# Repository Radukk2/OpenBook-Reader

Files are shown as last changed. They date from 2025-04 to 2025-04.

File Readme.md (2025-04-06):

# OpenBook Reader - Project
Block Chart : Block_chart.png file in the root of the directory

Bill of Materials : The bill of materials file can be found at /Manufacturing/Bom.csv

Hardware description
1. Microcontroller - ESP32-C6-WROOM-1-N8
    CPU: 32-bit RISC-V single-core @ up to 160MHz
    Memory: 320KB ROM, 512KB HP SRAM, 16KB LP SRAM
    Connectivity: Wi-Fi 6, Bluetooth LE 5.0
    Interfaces: GPIO, SPI, UART, I2C, PWM   
    Operating Voltage: 3.3V

   - The given microcontroller uses the following power modes: 
        When the device is active it consumes from 160 to 260 mA.
        When modem sleeps it ranges from 3 to 20 mA.
        On light the device consumes 0.8 mA.
        In Deep-sleep mode it consumes 10 μA.
        Hibernation modes consumes 2.5 μA.

2. Display Interface 7.5" E-Paper Display
    - Interface: SPI via FPC connector
    - Pins:   EPD_CS: GPIO10
            EPD_DC: GPIO5
            EPD_RST: GPIO23
            EPD_BUSY: GPIO3
            MOSI, SCK: Shared with SD card
            Used pins : Pins.xlsx  provieds the full ecplination

    The reasons why we use ePaper is for: 
                                        - ultra-low power consumption
                                        - excellent sunlight readability
3. Storage Solutions
    - MicroSD Card with the SPI interface.
    - 64MB NOR Flash with the same SPI interface.

4. Real time clocks
    We use a DS3231SN model for its high accuracy, backup supported battery.

5. Power Management
    USB-C Interface 
    MCP73831 - Li-Po Battery Charging that is used for charging

6. Buttons
    There are also 3 buttons: reset, boot and change. These are used for user's interaction with the device.

Used Pins: Described fully in Pins.xlsx

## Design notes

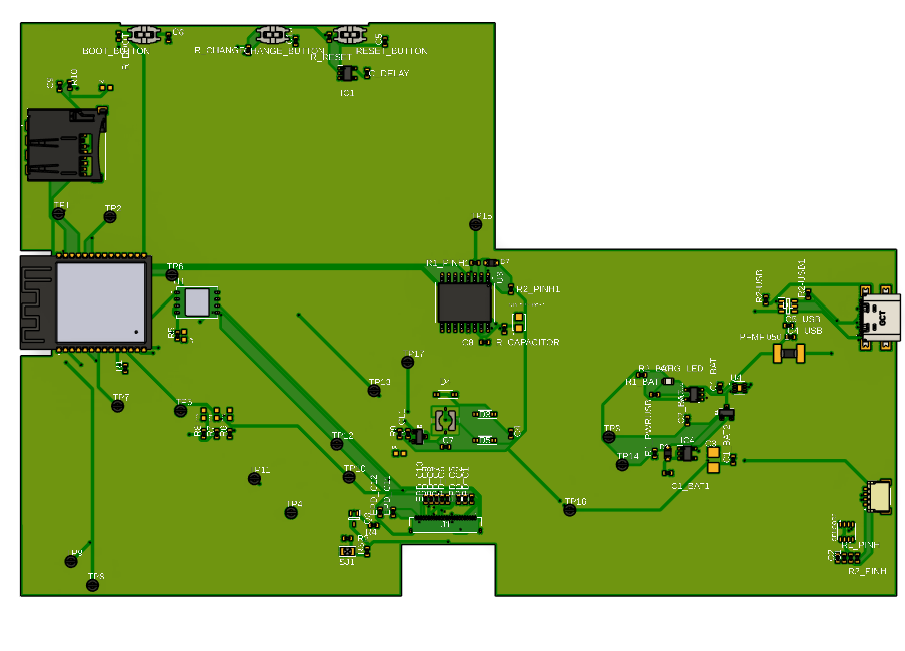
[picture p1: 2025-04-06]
Images/board1.png

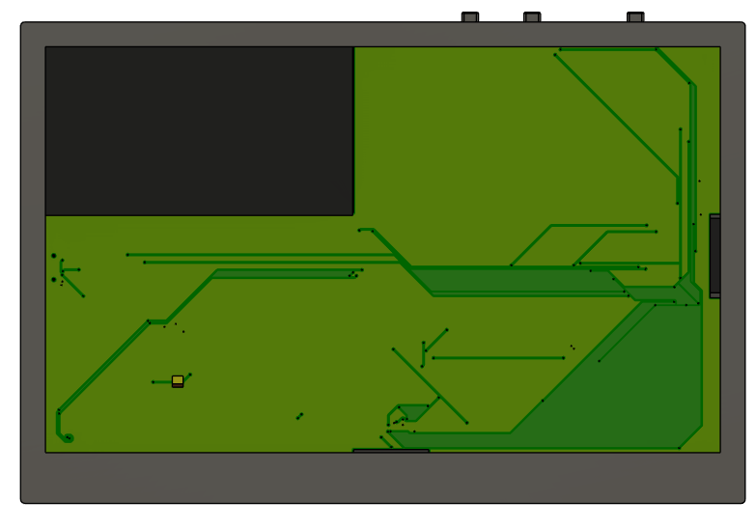
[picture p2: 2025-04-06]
Images/battery_and_front_no screen.png

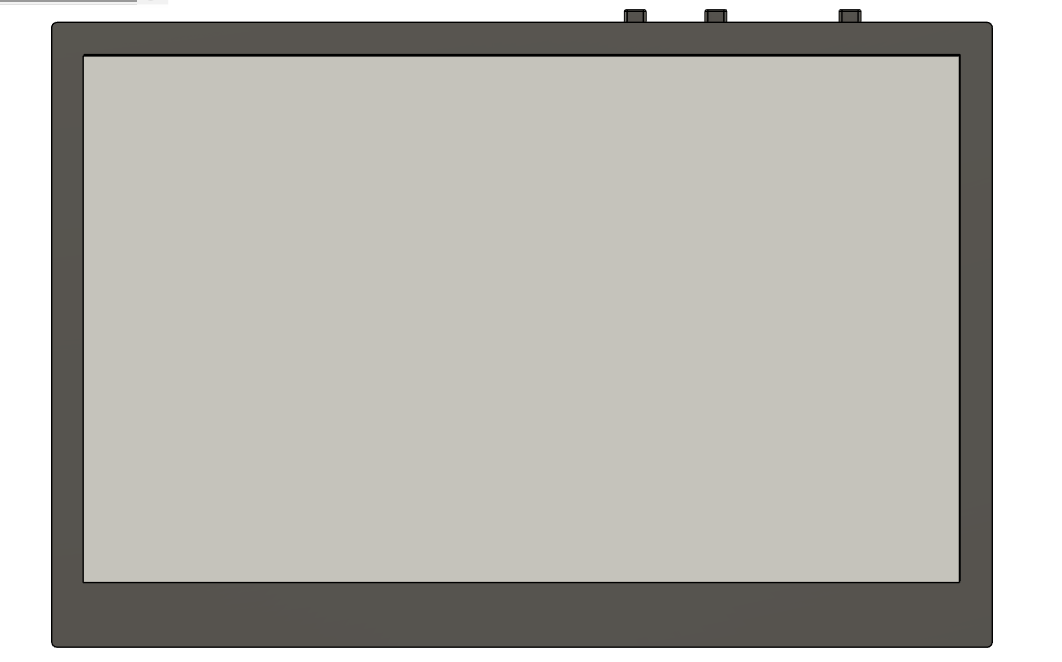
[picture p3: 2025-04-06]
Images/Front.png

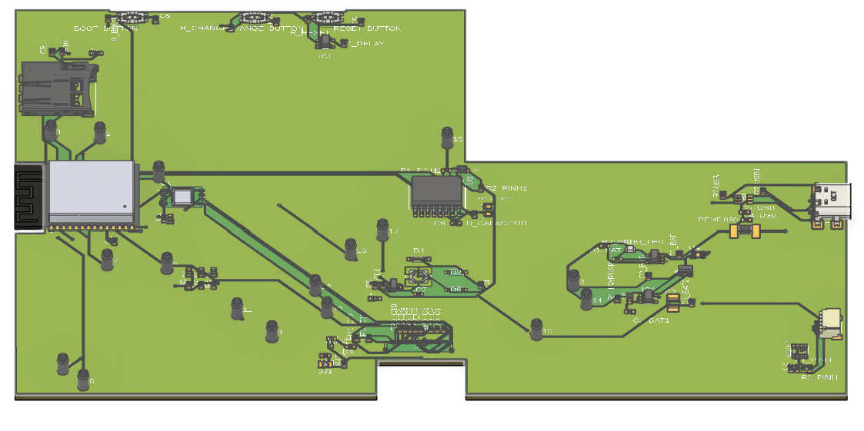
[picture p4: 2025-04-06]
Images/board2.png

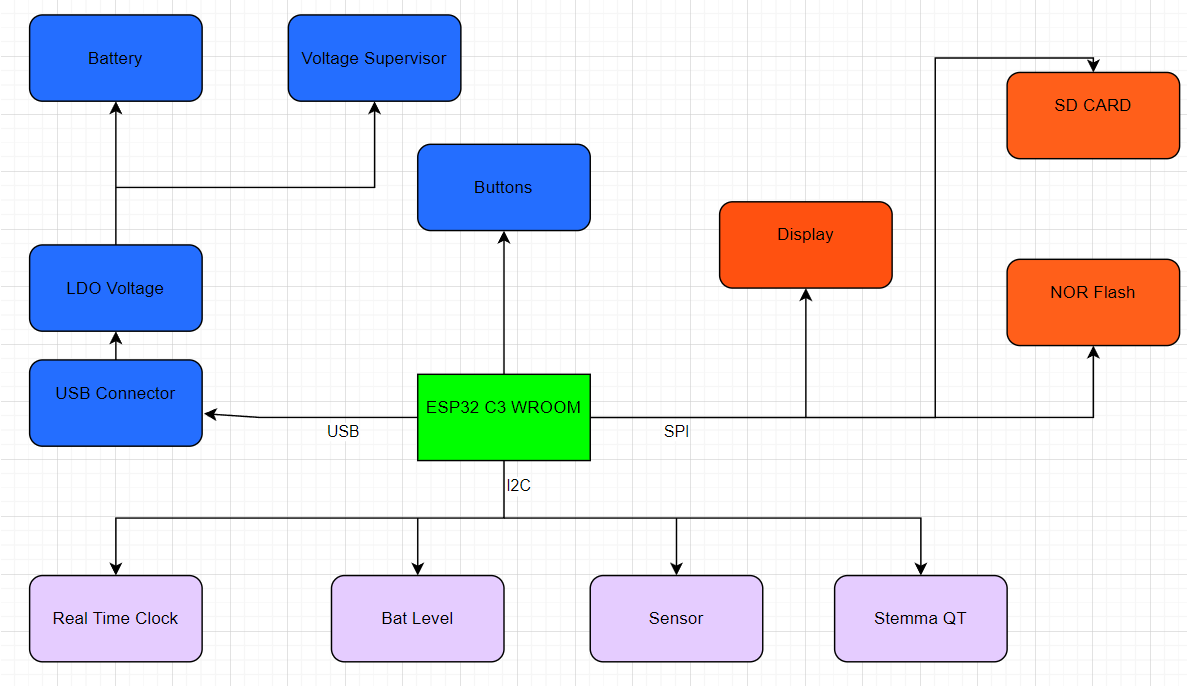
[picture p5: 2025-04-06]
Block_Chart.png

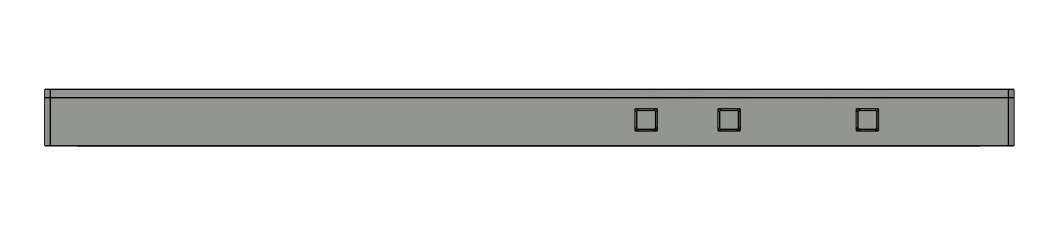
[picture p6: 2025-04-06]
Images/buttons.png

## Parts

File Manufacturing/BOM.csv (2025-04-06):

Qty | Value | Device | Package | Parts | Description | ARROW_PART_NUMBER | ARROW_PRICE-STOCK | AVAILABILITY | CENTROID_NOT_SPECIFIED | CHECK_PRICES | COPYRIGHT | DATASHEET | DESCRIPTION | DIGIKEY_DESCRIPTION | DIGIKEY_PART_NUMBER | HEIGHT | LEAD_FREE | MANUFACTURER_NAME | MANUFACTURER_PART_NUMBER | MF | MFR_NAME | MOUSER_PART_NUMBER | MOUSER_PRICE-STOCK | MOUSER_TESTING_PART_NUMBER | MOUSER_TESTING_PRICE-STOCK | MP | MPN | PACKAGE | POPULARITY | PREFIX | PRICE | PROD_ID | PURCHASE-URL | ROHS | SNAPEDA_LINK | SPICEMODEL | SPICEPREFIX | TEMPERATURE_RANGE_HIGH | TEMPERATURE_RANGE_LOW | TP_SIGNAL_NAME | VALUE
1 |  | ADAFRUIT_LEDCHIP-LED0603 | ADAFRUIT_CHIP-LED0603 | CHG_LED | LED |  |  |  |  | https://www.snapeda.com/parts/KP-1608SURCK/Kingbright/view-part/?ref=search&t=LED%200603
5 |  | EAGLE-LTSPICE_CC0402 | EAGLE-LTSPICE_C0402 | C1, C2, C5, C7, EPD_C9 | CAPACITOR, European symbol |  |  |  |  | https://grabcad.com/library/solder-jumpers-1 |  |  |  |  |  |  |  |  |  |  |  |  |  |  |  |  |  |  |  |  |  |  |  |  |  | NONE | C
1 |  | ESP32_WROVER_EAGLE-LTSPICE_RR0402 | ESP32_WROVER_EAGLE-LTSPICE_R0402 | R2 | RESISTOR, European symbol |  |  |  |  | https://eu.mouser.com/ProductDetail/KEMET/C0805C104K8RACAUTO?qs=ds50AKTGxA8vmn6TMGYnqg%3D%3D |  |  |  |  |  |  |  |  |  |  |  |  |  |  |  |  |  |  |  |  |  |  |  |  |  | NONE | R
1 |  | SJ | SJ | SJ1 | SMD solder JUMPER |  |  |  |  | https://componentsearchengine.com/part-view/R0402%201%25%20100%20K%20(RC0402FR-07100KL)/YAGEO |  |  |  |  |  |  |  |  |  |  |  |  |  |  |  |  |  |  | 3
1 | 0.1uF/50V | EAGLE-LTSPICE_CC0402 | EAGLE-LTSPICE_C0402 | EPD_C5 | CAPACITOR, European symbol |  |  |  |  | https://componentsearchengine.com/part-view/R0402%201%25%20100%20K%20(RC0402FR-07100KL)/YAGEO |  |  |  |  |  |  |  |  |  |  |  |  |  |  |  |  |  |  |  |  |  |  |  |  |  | NONE | C
1 | 0.47 | ESP32_WROVER_EAGLE-LTSPICE_RR0402 | ESP32_WROVER_EAGLE-LTSPICE_R0402 | R3 | RESISTOR, European symbol |  |  |  |  | https://eu.mouser.com/ProductDetail/KEMET/C0805C104K8RACAUTO?qs=ds50AKTGxA8vmn6TMGYnqg%3D%3D |  |  |  |  |  |  |  |  |  |  |  |  |  |  |  |  |  |  |  |  |  |  |  |  |  | NONE | R
1 | 100K | ESP32_WROVER_EAGLE-LTSPICE_RR0402 | ESP32_WROVER_EAGLE-LTSPICE_R0402 | R1_PWRUSB | RESISTOR, European symbol |  |  |  |  | https://www.snapeda.com/parts/20TDC100MYF/Panasonic/view-part/ |  |  |  |  |  |  |  |  |  |  |  |  |  |  |  |  |  |  |  |  |  |  |  |  |  | NONE | R
5 | 100nF | EAGLE-LTSPICE_CC0402 | EAGLE-LTSPICE_C0402 | C4_USB, C6, C8, C9, C_DELAY | CAPACITOR, European symbol |  |  |  |  | https://componentsearchengine.com/part-view/R0402%201%25%20100%20K%20(RC0402FR-07100KL)/YAGEO |  |  |  |  |  |  |  |  |  |  |  |  |  |  |  |  |  |  |  |  |  |  |  |  |  | NONE | C
1 | 100uF | RCL_CPOL-EUCT3528 | RCL_CT3528 | C3 | POLARIZED CAPACITOR, European symbol |  |  |  |  | https://eu.mouser.com/ProductDetail/KEMET/C0805C104K8RACAUTO?qs=ds50AKTGxA8vmn6TMGYnqg%3D%3D |  |  |  |  |  |  |  |  |  |  |  |  |  |  |  |  |  |  | 0 |  |  |  |  |  |  |  | C
16 | 10K | ESP32_WROVER_EAGLE-LTSPICE_RR0402 | ESP32_WROVER_EAGLE-LTSPICE_R0402 | R1, R1_PINH, R1_PINH1, R2_PINH, R2_PINH1, R4, R5, R6, R7, R8, R9, R10, R_BOOT, R_CHANGE, R_CL1, R_RESET | RESISTOR, European symbol |  |  |  |  | https://store.comet.srl.ro/Catalogue/Product/43497/ |  |  |  |  |  |  |  |  |  |  |  |  |  |  |  |  |  |  |  |  |  |  |  |  |  | NONE | R
1 | 10nF | EAGLE-LTSPICE_CC0402 | EAGLE-LTSPICE_C0402 | C10 | CAPACITOR, European symbol |  |  |  |  | https://componentsearchengine.com/part-view/R0402%201%25%20100%20K%20(RC0402FR-07100KL)/YAGEO |  |  |  |  |  |  |  |  |  |  |  |  |  |  |  |  |  |  |  |  |  |  |  |  |  | NONE | C
1 | 10uF/50 | EAGLE-LTSPICE_CC0402 | EAGLE-LTSPICE_C0402 | EPD_C10 | CAPACITOR, European symbol |  |  |  |  | https://eu.mouser.com/ProductDetail/KEMET/C0805C104K8RACAUTO?qs=ds50AKTGxA8vmn6TMGYnqg%3D%3D |  |  |  |  |  |  |  |  |  |  |  |  |  |  |  |  |  |  |  |  |  |  |  |  |  | NONE | C
1 | 112A-TAAR-R03_ATTEND | 112A-TAAR-R03_ATTEND | 112ATAARR03ATTEND | J4 | Micro SD Card Socket, Push-Push Type, Top Mount, SMT, H=1.83mm, 10u |  |  |  |  | https://eu.mouser.com/ProductDetail/KEMET/C0805C104K8RACAUTO?qs=ds50AKTGxA8vmn6TMGYnqg%3D%3D |  |  | Micro SD Card Socket | Push-Push Type | Top Mount | SMT | H=1.83mm | 10u |  |  | 1.9mm |  | ATTEND | 112A-TAAR-R03 ATTEND
1 | 15 | ESP32_WROVER_EAGLE-LTSPICE_RR0402 | ESP32_WROVER_EAGLE-LTSPICE_R0402 | R_CAPACITOR | RESISTOR, European symbol |  |  |  |  | https://componentsearchengine.com/part-view/R0402%201%25%20100%20K%20(RC0402FR-07100KL)/YAGEO |  |  |  |  |  |  |  |  |  |  |  |  |  |  |  |  |  |  |  |  |  |  |  |  |  | NONE | R
7 | 1uF/50V | EAGLE-LTSPICE_CC0402 | EAGLE-LTSPICE_C0402 | EPD_C1, EPD_C2, EPD_C6, EPD_C7, EPD_C8, EPD_C11, EPD_C12 | CAPACITOR, European symbol |  |  |  |  | https://componentsearchengine.com/part-view/R0402%201%25%20100%20K%20(RC0402FR-07100KL)/YAGEO |  |  |  |  |  |  |  |  |  |  |  |  |  |  |  |  |  |  |  |  |  |  |  |  |  | NONE | C
1 | 200 | ESP32_WROVER_EAGLE-LTSPICE_RR0402 | ESP32_WROVER_EAGLE-LTSPICE_R0402 | R1_BAT | RESISTOR, European symbol |  |  |  |  | https://componentsearchengine.com/part-view/DMG2305UX-7/Diodes%20Incorporated |  |  |  |  |  |  |  |  |  |  |  |  |  |  |  |  |  |  |  |  |  |  |  |  |  | NONE | R
2 | 20V/4.2A/52mO/1.4W | ESP32_WROVER_SPARKFUN-DISCRETESEMI_MOSFET_PCH-DMG2305UX-7 | ESP32_WROVER_SPARKFUN-DISCRETESEMI_SOT23-3 | Q1, Q2 | P-channel MOSFETs |  |  |  |  | https://componentsearchengine.com/part-view/DMG2305UX-7/Diodes%20Incorporated |  |  |  |  |  |  |  |  |  |  |  |  |  |  |  |  |  |  |  |  |  | TRAN-14388 |  |  |  |  |  |  |  |  | 20V/4.2A/52mO/1.4W
1 | 2K | ESP32_WROVER_EAGLE-LTSPICE_RR0402 | ESP32_WROVER_EAGLE-LTSPICE_R0402 | R2_BAT | RESISTOR, European symbol |  |  |  |  | https://componentsearchengine.com/part-view/R0402%201%25%20100%20K%20(RC0402FR-07100KL)/YAGEO |  |  |  |  |  |  |  |  |  |  |  |  |  |  |  |  |  |  |  |  |  |  |  |  |  | NONE | R
5 | 4.7uF | EAGLE-LTSPICE_CC0402 | EAGLE-LTSPICE_C0402 | C1_BAT, C1_BAT1, C1_BAT2, C2_BAT, C5_USB | CAPACITOR, European symbol |  |  |  |  | https://eu.mouser.com/ProductDetail/KEMET/C0805C104K8RACAUTO?qs=ds50AKTGxA8vmn6TMGYnqg%3D%3D |  |  |  |  |  |  |  |  |  |  |  |  |  |  |  |  |  |  |  |  |  |  |  |  |  | NONE | C
1 | 4.7uF/25V | EAGLE-LTSPICE_CC0402 | EAGLE-LTSPICE_C0402 | C4 | CAPACITOR, European symbol |  |  |  |  | https://eu.mouser.com/ProductDetail/KEMET/C0805C104K8RACAUTO?qs=ds50AKTGxA8vmn6TMGYnqg%3D%3D |  |  |  |  |  |  |  |  |  |  |  |  |  |  |  |  |  |  |  |  |  |  |  |  |  | NONE | C
2 | 5k1 | ESP32_WROVER_EAGLE-LTSPICE_RR0402 | ESP32_WROVER_EAGLE-LTSPICE_R0402 | R2-USB, R2-USB1 | RESISTOR, European symbol |  |  |  |  | https://componentsearchengine.com/part-view/R0402%201%25%20100%20K%20(RC0402FR-07100KL)/YAGEO |  |  |  |  |  |  |  |  |  |  |  |  |  |  |  |  |  |  |  |  |  |  |  |  |  | NONE | R
1 | 744043680IND_4828-WE-TPC_WRE | 744043680IND_4828-WE-TPC_WRE | IND_4828-WE-TPC_WRE | L1 |  |  |  |  |  | https://eu.mouser.com/ProductDetail/Wurth-Elektronik/744043680?qs=PGXP4M47uW6VkZq%252BkzjrHA%3D%3D | Copyright (C) 2024 Ultra Librarian. All rights reserved. |  |  |  |  |  |  |  | 744043680 |  | Wurth Electronics
1 | BD5229G-TR | BD5229G-TR | SOT95P280X125-5N | IC1 | Voltage Detector with Adjustable Delay Time: CMOS processes are utilized to develop high precision, low current consumption CMOS reset ICs that allow arbitrary setting of the delay time. The extensive lineup includes both Nch Open Drain and CMOS output types in a wide range of detection voltages (from 2.3V to 6.0V, in 0.1V steps), enabling selection of the ideal solution based on customer requirements. In addition, the entire series is of course both lead-free and RoHS-compliant. |  |  |  |  | https://componentsearchengine.com/part-view/BD5229G-TR/ROHM%20Semiconductor |  |  | Voltage Detector with Adjustable Delay Time: CMOS processes are utilized to develop high precision | low current consumption CMOS reset ICs that allow arbitrary setting of the delay time. The extensive lineup includes both Nch Open Drain and CMOS output types in a wide range of detection voltages (from 2.3V to 6.0V | in 0.1V steps) | enabling selection of the ideal solution based on customer requirements. In addition | the entire series is of course both lead-free and RoHS-compliant. |  |  | 1.25mm |  | ROHM Semiconductor | BD5229G-TR |  |  | 755-BD5229G-TR | https://www.mouser.co.uk/ProductDetail/ROHM-Semiconductor/BD5229G-TR?qs=4kLU8WoGk0vvnhrrYwdszw%3D%3D
3 | BUTTON_CUSYOMV1 | BUTTON_CUSYOMV1 | MYBUTTON | BOOT_BUTTON, CHANGE_BUTTON, RESET_BUTTON |  |  |  |  |  | https://industry.panasonic.com/global/en/products/control/switch/light-touch/number/evqpuj02k
1 | CPH3225A | CPH3225A | CAPCP3225X100N | C10_SUPERCAP | Cap 0.011F 3.3V 1210 Flat Check availability |  |  | Not in stock |  | https://www.snapeda.com/parts/CPH3225A/Seiko+Instruments/view-part/?ref=eda |  |  | 11 mF (EDLC) Supercapacitor 3.3 V 1210 (3225 Metric) - - |  |  |  |  |  |  | Seiko Instruments |  |  |  |  |  | CPH3225A |  | 1210 Seiko |  |  | None |  | https://www.snapeda.com/api/url_track_click_mouser/?unipart_id=562593&manufacturer=Seiko Instruments&part_name=CPH3225A&search_term=None |  | https://www.snapeda.com/parts/CPH3225A/Seiko+Instruments/view-part/?ref=snap
1 | DS3231SN# | DS3231SN# | SOIC127P1032X265-16N | U3 | Real Time Clock Serial 16-Pin SOIC W T/R Check availability |  |  | In Stock |  | https://www.snapeda.com/parts/DS3231SN%23/Analog+Devices/view-part/?ref=eda |  |  | Extremely Accurate I²C-Integrated RTC/TCXO/Crystal |  |  |  |  |  |  | Analog Devices |  |  |  |  |  | DS3231SN# |  | SOIC-16 Maxim |  |  | None |  | https://www.snapeda.com/api/url_track_click_mouser/?unipart_id=99048&manufacturer=Analog Devices&part_name=DS3231SN#&search_term=None |  | https://www.snapeda.com/parts/DS3231SN%23/Analog+Devices/view-part/?ref=snap
1 | ESP32-C6-WROOM-1-N8 | ESP32-C6-WROOM-1-N8 | XCVR_ESP32-C6-WROOM-1-N8 | U2 | Check availability |  |  | In Stock |  | https://www.snapeda.com/parts/ESP32-C6-WROOM-1-N8/Espressif+Systems/view-part/?ref=eda |  |  | Multiprotocol Modules ESP32-C6 module | Wi-Fi 6 in 2.4 GHz band | Bluetooth 5 | Zigbee 3.0 and Thread. ESP34-WROOM Compatible - ENGINEERING SAMPLE |  |  |  |  |  |  | Espressif Systems |  |  |  |  |  | ESP32-C6-WROOM-1-N8 |  | None |  |  | None |  |  |  | https://www.snapeda.com/parts/ESP32-C6-WROOM-1-N8/Espressif+Systems/view-part/?ref=snap
1 | ESP32C6_VARISTORCN1812 | ESP32C6_VARISTORCN1812 | ESP32C6_VARISTOR_CT/CN1812 | PFMF.050.1 | VARISTOR |  |  |  |  | https://www.mouser.co.uk/ProductDetail/EPCOS-TDK/B72520T0350K062?qs=dEfas%2FXlABIszF52uu7vrg%3D%3D |  |  |  |  |  |  |  |  |  |  |  |  |  |  |  |  |  |  | 0
2 | ESP32_WROVER_AVX---SD0805S020S1R0_AVX_SD0805S020S1R0_0_0AVX_SD0805S020S1R0_0_0 | ESP32_WROVER_AVX---SD0805S020S1R0_AVX_SD0805S020S1R0_0_0AVX_SD0805S020S1R0_0_0 | ESP32_WROVER_AVX---SD0805S020S1R0_AVX_SD0805S020S1R0_0 | D2, D7 | Schottky Barrier Rectifier Diode |  |  |  | No | https://eu.mouser.com/ProductDetail/KYOCERA-AVX/SD0805S020S1R0?qs=jCA%252BPfw4LHbpkAoSnwrdjw%3D%3D |  | http://datasheets.avx.com/schottky.pdf |  | DIODE SCHOTTKY 20V 1A 0805 | 478-7800-1-ND |  | yes |  |  | AVX |  | 581-SD0805S020S1R0 |  |  |  |  |  | 0805 (2012 metric) |  | D |  |  |  | yes |  |  |  | +125°C | -55°C
1 | ESP32_WROVER_BME680_BME680 | ESP32_WROVER_BME680_BME680 | ESP32_WROVER_BME680_PSON80P300X300X100-8N | SENSOR2 | Integrated Environmental Unit |  |  | Unavailable |  | https://www.snapeda.com/parts/BME680/Bosch/view-part/?welcome=home |  |  | Integrated Environmental Unit |  |  |  |  |  |  | Bosch Sensortec |  |  |  |  |  | BME680 |  | LGA-8 Bosch Tools |  |  | None
1 | ESP32_WROVER_SPARKFUN-IC-POWER_MCP73831 | ESP32_WROVER_SPARKFUN-IC-POWER_MCP73831 | ESP32_WROVER_SPARKFUN-IC-POWER_SOT23-5 | MCP73831 | MCP73831T Li-Ion, Li-Pol Controller |  |  |  |  | https://www.digikey.ro/en/products/detail/microchip-technology/MCP73831T-2ACI-OT/964301 |  |  |  |  |  |  |  |  |  |  |  |  |  |  |  |  |  |  |  |  |  | IC-09995
1 | FH34SRJ-24S-0.5SH_99_ | FH34SRJ-24S-0.5SH_99_ | FH34SRJ24S05SH99 | J1 | (0.50mm) Surface Mount, Right Angle |  |  |  |  | https://componentsearchengine.com/part-view/XC6220A331MR-G/Torex |  |  | 24 Position FFC | FPC Connector Contacts | (0.50mm) Surface Mount | Right Angle |  |  | 1.1mm |  | Hirose | FH34SRJ-24S-0.5SH(99) |  |  | 798-FH34SRJ24S05SH99 | https://www.mouser.co.uk/ProductDetail/Hirose-Connector/FH34SRJ-24S-0.5SH99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
1 | MAX17048G+T10 | MAX17048G+T10 | SON50P200X200X80-9N | U4 | Check availability |  |  | In Stock |  | https://www.snapeda.com/parts/MAX17048G+T10/Analog+Devices/view-part/?ref=eda |  |  | 3µA 1-Cell/2-Cell Fuel Gauge with ModelGauge |  |  |  |  |  |  | Analog Devices |  |  |  |  |  | MAX17048G+T10 |  | TDFN-8 Maxim |  |  | None |  | https://www.snapeda.com/api/url_track_click_mouser/?unipart_id=329239&manufacturer=Analog Devices&part_name=MAX17048G+T10&search_term=None |  | https://www.snapeda.com/parts/MAX17048G+T10/Analog+Devices/view-part/?ref=snap
3 | MBR0530 | MBR0530 | SOD3716X135N | D3, D4, D5 | ON SEMICONDUCTOR - MBR0530 - DIODE, SCHOTTKY, 0.5A, 30V, SOD-123 |  |  | In Stock |  | https://www.snapeda.com/parts/MBR0530/Onsemi/view-part/?ref=eda |  |  | Diode Schottky 30 V 500mA Surface Mount SOD-123 |  |  |  |  |  |  | ON Semiconductor |  |  |  |  |  | MBR0530 |  | SOD-123-2 ON Semiconductor |  |  | None |  | https://www.snapeda.com/api/url_track_click_mouser/?unipart_id=179458&manufacturer=ON Semiconductor&part_name=MBR0530&search_term=None |  | https://www.snapeda.com/parts/MBR0530/Onsemi/view-part/?ref=snap
6 | PGB1010603MR | PGB1010603MR | DIOC1608X36N | D6, D8, D9, D10, D11, D12 | Check availability |  |  | In Stock |  | https://www.snapeda.com/parts/PGB1010603MR/Littelfuse/view-part/?ref=eda |  |  | 150V (Typ) Clamp - Ipp Tvs Diode Surface Mount 0603 (1608 Metric) |  |  |  |  |  |  | Littelfuse Inc. |  |  |  |  |  | PGB1010603MR |  | 0603 Littelfuse Inc. |  |  | None |  | https://www.snapeda.com/api/url_track_click_mouser/?unipart_id=5659453&manufacturer=Littelfuse Inc.&part_name=PGB1010603MR&search_term=None |  | https://www.snapeda.com/parts/PGB1010603MR/Littelfuse/view-part/?ref=snap
1 | QWIIC_RIGHT_ANGLE | QWIIC_CONNECTORJS-1MM | JST04_1MM_RA | J3 | SparkFun I2C Standard Qwiic Connector |  |  |  |  | https://www.digikey.ro/en/models/926710 |  |  |  |  |  |  |  |  |  |  |  |  |  |  |  |  |  |  |  |  |  | CONN-13694 |  |  |  |  |  |  |  |  | QWIIC_RIGHT_ANGLE
1 | SAMACSYS_PARTS_USB4110-GF-A | SAMACSYS_PARTS_USB4110-GF-A | SAMACSYS_PARTS_USB4110GFA | J2 | CONN USB 2.0 TYPE-C R/A SMT |  |  |  |  | https://componentsearchengine.com/part-view/USB4110-GF-A/GCT%20(GLOBAL%20CONNECTOR%20TECHNOLOGY) |  |  | CONN USB 2.0 TYPE-C R/A SMT |  |  | 3.26mm |  | GCT (GLOBAL CONNECTOR TECHNOLOGY) | USB4110-GF-A |  |  | 640-USB4110-GF-A | https://www.mouser.co.uk/ProductDetail/GCT/USB4110-GF-A?qs=KUoIvG%2F9IlYiZvIXQjyJeA%3D%3D
1 | SI1308EDL-T1-GE3 | SI1308EDL-T1-GE3 | SOT65P210X110-3N | Q3 | MOSFET N-Ch 30V 1.5A TrenchFET SC70 Vishay Si1308EDL-T1-GE3 N-channel MOSFET Transistor, 1.5 A, 30 V, 3-Pin SC-70 |  |  | In Stock |  | https://www.snapeda.com/parts/SI1308EDL-T1-GE3/Vishay+Siliconix/view-part/?ref=eda |  |  | Si1308EDL-T1-GE3 N-channel MOSFET Transistor | 1.5 A | 30 V | 3-Pin SC-70 | Siliconix / Vishay SI1308EDL-T1-GE3 |  |  |  |  |  |  | Vishay Siliconix |  |  |  |  |  | SI1308EDL-T1-GE3 |  | SOT-323 Vishay Semiconductor |  |  | None |  | https://www.snapeda.com/api/url_track_click_mouser/?unipart_id=274603&manufacturer=Vishay Siliconix&part_name=SI1308EDL-T1-GE3&search_term=None |  | https://www.snapeda.com/parts/SI1308EDL-T1-GE3/Vishay+Siliconix/view-part/?ref=snap
17 | TPTP20R | TPTP20R | TP20R | TP1, TP2, TP3, TP4, TP5, TP6, TP7, TP8, TP9, TP10, TP11, TP12, TP13, TP14, TP15, TP16, TP17 | Test pad |  |  |  |  | https://grabcad.com/library/test-points-printed-circuit-board-1 |  |  |  |  |  |  |  |  |  |  |  |  |  |  |  |  |  |  | 2
1 | USBLC6-2SC6Y | USBLC6-2SC6Y | SOT95P280X145-6N | D1 | Low Cap. ESD Protection Auto SOT-23-6 STMicroelectronics USBLC6-2SC6Y, Dual Uni-Directional TVS Diode Array, 6-Pin SOT-23 |  |  | In Stock |  | https://www.snapeda.com/parts/USBLC6-2SC6Y/STMicroelectronics/view-part/?ref=eda |  |  | 17V Clamp 5A (8/20µs) Ipp Tvs Diode Surface Mount SOT-23-6 |  |  |  |  |  |  | STMicroelectronics |  |  |  |  |  | USBLC6-2SC6Y |  | SOT-23-6 STMicroelectronics |  |  | None |  |  |  | https://www.snapeda.com/parts/USBLC6-2SC6Y/STMicroelectronics/view-part/?ref=snap
1 | W25Q512JVEIQ | W25Q512JVEIQ | SON127P600X800X80-9N | U1 | Check availability |  |  | In Stock |  | https://www.snapeda.com/parts/W25Q512JVEIQ/Winbond+Electronics/view-part/?ref=eda |  |  | FLASH - NOR Memory IC 512Mb (64M x 8) SPI - Quad I/O 133 MHz 8-WSON (8x6) |  |  |  |  |  |  | Winbond Electronics |  |  |  |  |  | W25Q512JVEIQ |  | Package |  |  | None |  |  |  | https://www.snapeda.com/parts/W25Q512JVEIQ/Winbond+Electronics/view-part/?ref=snap
1 | XC6220A331MR-G | XC6220A331MR-G | SOT95P280X120-5N | IC4 | LDO Voltage Regulators |  |  |  |  |  |  |  | LDO Voltage Regulators |  |  | 1.2mm |  | Torex | XC6220A331MR-G |  |  | 865-XC6220A331MR-G | https://www.mouser.co.uk/ProductDetail/Torex-Semiconductor/XC6220A331MR-G?qs=AsjdqWjXhJ8ZSWznL1J0gg%3D%3D

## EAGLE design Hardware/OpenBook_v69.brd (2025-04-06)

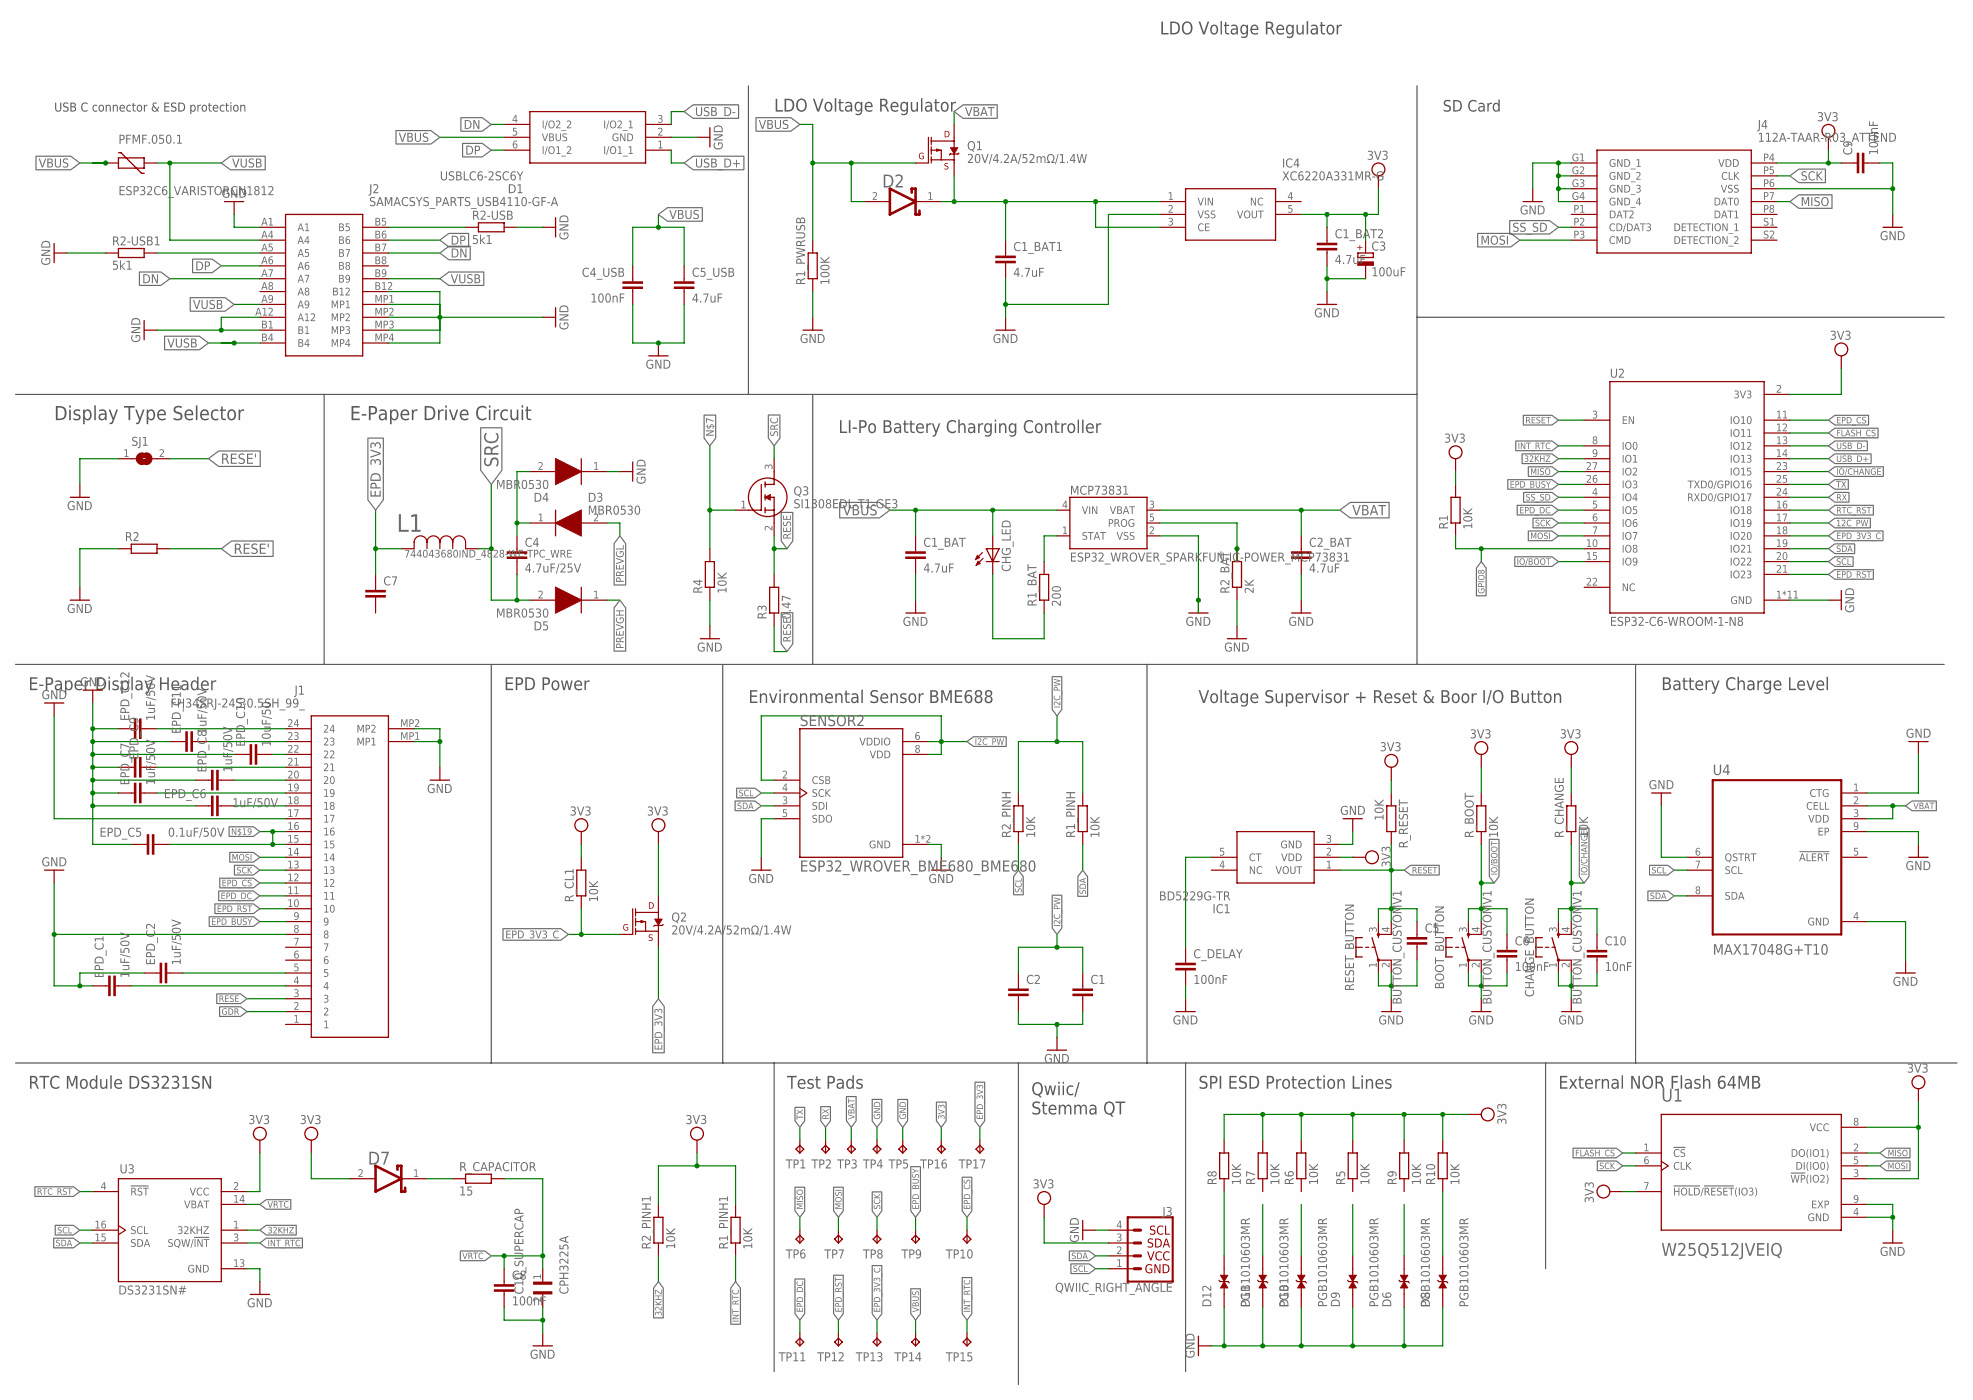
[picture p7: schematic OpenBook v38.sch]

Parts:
BOOT_BUTTON: BUTTON_CUSYOMV1; MYBUTTON
C1, C2, C5, C7: EAGLE-LTSPICE_CC0402; EAGLE-LTSPICE_C0402
C1_BAT, C1_BAT1, C1_BAT2, C2_BAT, C5_USB: 4.7uF; EAGLE-LTSPICE_C0402
C3: 100uF; RCL_CT3528
C4: 4.7uF/25V; EAGLE-LTSPICE_C0402
C4_USB, C6, C8, C9: 100nF; EAGLE-LTSPICE_C0402
C10: 10nF; EAGLE-LTSPICE_C0402
C10_SUPERCAP: CPH3225A; CAPCP3225X100N
CHANGE_BUTTON: BUTTON_CUSYOMV1; MYBUTTON
CHG_LED: ADAFRUIT_LEDCHIP-LED0603; ADAFRUIT_CHIP-LED0603
C_DELAY: 100nF; EAGLE-LTSPICE_C0402
D1: USBLC6-2SC6Y; SOT95P280X145-6N
D2, D7: ESP32_WROVER_AVX---SD0805S020S1R0_AVX_SD0805S020S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; ESP32_WROVER_AVX---SD0805S020S1R0_AVX_SD0805S020S1R0_0
D3, D4, D5: MBR0530; SOD3716X135N
D6, D8, D9, D10, D11, D12: PGB1010603MR; DIOC1608X36N
EPD_C1, EPD_C2, EPD_C6, EPD_C7, EPD_C8, EPD_C11, EPD_C12: 1uF/50V; EAGLE-LTSPICE_C0402
EPD_C5: 0.1uF/50V; EAGLE-LTSPICE_C0402
EPD_C9: EAGLE-LTSPICE_CC0402; EAGLE-LTSPICE_C0402
EPD_C10: 10uF/50; EAGLE-LTSPICE_C0402
IC1: BD5229G-TR; SOT95P280X125-5N
IC4: XC6220A331MR-G; SOT95P280X120-5N
J1: FH34SRJ-24S-0.5SH_99_; FH34SRJ24S05SH99
J2: SAMACSYS_PARTS_USB4110-GF-A; SAMACSYS_PARTS_USB4110GFA
J3: QWIIC_RIGHT_ANGLE; JST04_1MM_RA
J4: 112A-TAAR-R03_ATTEND; 112ATAARR03ATTEND
L1: 744043680IND_4828-WE-TPC_WRE; IND_4828-WE-TPC_WRE
MCP73831: ESP32_WROVER_SPARKFUN-IC-POWER_MCP73831; ESP32_WROVER_SPARKFUN-IC-POWER_SOT23-5
PFMF.050.1: ESP32C6_VARISTORCN1812; ESP32C6_VARISTOR_CT/CN1812
Q1, Q2: 20V/4.2A/52mΩ/1.4W; ESP32_WROVER_SPARKFUN-DISCRETESEMI_SOT23-3
Q3: SI1308EDL-T1-GE3; SOT65P210X110-3N
R1, R1_PINH, R1_PINH1, R2_PINH, R2_PINH1, R4, R5, R6, R7, R8, R9, R10: 10K; ESP32_WROVER_EAGLE-LTSPICE_R0402
R1_BAT: 200; ESP32_WROVER_EAGLE-LTSPICE_R0402
R1_PWRUSB: 100K; ESP32_WROVER_EAGLE-LTSPICE_R0402
R2: ESP32_WROVER_EAGLE-LTSPICE_RR0402; ESP32_WROVER_EAGLE-LTSPICE_R0402
R2-USB, R2-USB1: 5k1; ESP32_WROVER_EAGLE-LTSPICE_R0402
R2_BAT: 2K; ESP32_WROVER_EAGLE-LTSPICE_R0402
R3: 0.47; ESP32_WROVER_EAGLE-LTSPICE_R0402
RESET_BUTTON: BUTTON_CUSYOMV1; MYBUTTON
R_BOOT: 10K; ESP32_WROVER_EAGLE-LTSPICE_R0402
R_CAPACITOR: 15; ESP32_WROVER_EAGLE-LTSPICE_R0402
R_CHANGE: 10K; ESP32_WROVER_EAGLE-LTSPICE_R0402
R_CL1: 10K; ESP32_WROVER_EAGLE-LTSPICE_R0402
R_RESET: 10K; ESP32_WROVER_EAGLE-LTSPICE_R0402
SENSOR2: ESP32_WROVER_BME680_BME680; ESP32_WROVER_BME680_PSON80P300X300X100-8N
SJ1: SJ
TP1, TP2, TP3, TP4, TP5, TP6, TP7, TP8, TP9, TP10, TP11, TP12, TP13, TP14, TP15, TP16, TP17: TPTP20R; TP20R
U1: W25Q512JVEIQ; SON127P600X800X80-9N
U2: ESP32-C6-WROOM-1-N8; XCVR_ESP32-C6-WROOM-1-N8
U3: DS3231SN#; SOIC127P1032X265-16N
U4: MAX17048G+T10; SON50P200X200X80-9N

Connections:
3V3: C1_BAT2.1, C3.+, C9.1, D7.2 (ANODE), IC1.2 (VDD), IC4.5 (VOUT), J3.3, J4.P4 (VDD), Q2.3 (D), R1.2, R1_PINH1.2, R2_PINH1.2, R5.2, R6.2, R7.2, R8.2, R9.2, R10.2, R_BOOT.2, R_CHANGE.2, R_CL1.2, R_RESET.1, TP16.TP, U1.3 (!WP!(IO2)), U1.7 (!HOLD!/!RESET!(IO3)), U1.8 (VCC), U2.2 (3V3), U3.2 (VCC)
12C_PW: U2.17 (IO19)
32KHZ: R2_PINH1.1, U2.9 (IO1), U3.1 (32KHZ)
DN: D1.4 (I/O2_2), J2.A7, J2.B7
DP: D1.6 (I/O1_2), J2.A6, J2.B6
EPD_3V3: C7.1, L1.2, Q2.2 (S), TP17.TP
EPD_3V3_C: Q2.1 (G), R_CL1.1, TP13.TP, U2.18 (IO20)
EPD_BUSY: J1.9, TP9.TP, U2.26 (IO3)
EPD_CS: J1.12, TP10.TP, U2.11 (IO10)
EPD_DC: J1.11, TP11.TP, U2.5 (IO5)
EPD_RST: J1.10, TP12.TP, U2.21 (IO23)
FLASH_CS: U1.1 (!CS), U2.12 (IO11)
GDR: J1.2
GND: BOOT_BUTTON.1, BOOT_BUTTON.2, C1.2, C1_BAT.2, C1_BAT1.2, C1_BAT2.2, C2.2, C2_BAT.2, C3.-, C4_USB.2, C5.2, C5_USB.2, C6.2, C8.2, C9.2, C10.2, C10_SUPERCAP.2, CHANGE_BUTTON.1, CHANGE_BUTTON.2, C_DELAY.2, D1.2 (GND), D4.1 (K), D6.1, D8.1, D9.1, D10.1, D11.1, D12.1, EPD_C1.1, EPD_C2.1, EPD_C5.1, EPD_C6.1, EPD_C7.1, EPD_C8.1, EPD_C9.1, EPD_C10.1, EPD_C11.1, EPD_C12.1, IC1.3 (GND), IC4.2 (VSS), J1.8, J1.17, J1.MP1, J1.MP2, J2.A1, J2.A12, J2.B1, J2.B12, J2.MP1, J2.MP2, J2.MP3, J2.MP4, J3.4, J4.G1 (GND_1), J4.G2 (GND_2), J4.G3 (GND_3), J4.G4 (GND_4), J4.P6 (VSS), MCP73831.2 (VSS), R1_PWRUSB.1, R2.1, R2-USB.2, R2-USB1.1, R2_BAT.1, R4.1, RESET_BUTTON.1, RESET_BUTTON.2, SENSOR2.1 (GND), SENSOR2.5 (SDO), SENSOR2.7 (GND), SJ1.1, TP4.TP, TP5.TP, U1.4 (GND), U1.9 (EXP), U2.1 (GND), U2.28 (GND), U2.29_1 (GND), U2.29_2 (GND), U2.29_3 (GND), U2.29_4 (GND), U2.29_5 (GND), U2.29_6 (GND), U2.29_7 (GND), U2.29_8 (GND), U2.29_9 (GND), U3.13 (GND), U4.1 (CTG), U4.4 (GND), U4.6 (QSTRT), U4.9 (EP)
GPIO8: R1.1, U2.10 (IO8)
I2C_PW: C1.1, C2.1, R1_PINH.2, R2_PINH.2, SENSOR2.2 (CSB), SENSOR2.6 (VDDIO), SENSOR2.8 (VDD)
INT_RTC: R1_PINH1.1, TP15.TP, U2.8 (IO0), U3.3 (SQW/!INT)
IO/BOOT: BOOT_BUTTON.3, BOOT_BUTTON.4, C6.1, R_BOOT.1, U2.15 (IO9)
IO/CHANGE: C10.1, CHANGE_BUTTON.3, CHANGE_BUTTON.4, R_CHANGE.1, U2.23 (IO15)
MISO: J4.P7 (DAT0), TP6.TP, U1.2 (DO(IO1)), U2.27 (IO2)
MOSI: J1.14, J4.P3 (CMD), TP7.TP, U1.5 (DI(IO0)), U2.7 (IO7)
unnamed: J2.B5, R2-USB.1
unnamed: J2.A5, R2-USB1.2
unnamed: C1_BAT1.1, D2.1 (CATHODE), IC4.1 (VIN), IC4.3 (CE), Q1.2 (S)
unnamed: C4.1, D3.1 (K), D4.2 (A)
unnamed: MCP73831.5 (PROG), R2_BAT.2
unnamed: Q3.1 (G), R4.2
unnamed: EPD_C1.2, J1.4
unnamed: MCP73831.1 (STAT), R1_BAT.2
unnamed: CHG_LED.C, R1_BAT.1
unnamed: EPD_C2.2, J1.5
unnamed: EPD_C6.2, J1.18
unnamed: EPD_C7.2, J1.19
unnamed: EPD_C8.2, J1.20
unnamed: EPD_C9.2, J1.21
unnamed: EPD_C10.2, J1.22
unnamed: EPD_C12.2, J1.24
unnamed: EPD_C11.2, J1.23
unnamed: EPD_C5.2, J1.15, J1.16
unnamed: C_DELAY.1, IC1.5 (CT)
unnamed: D7.1 (CATHODE), R_CAPACITOR.1
unnamed: D12.2, R8.1
unnamed: D8.2, R10.1
PREVGH: D5.1 (K)
PREVGL: D3.2 (A)
RESE: J1.3, Q3.2 (S), R3.2
RESE': R2.2, R3.1, SJ1.2
RESET: C5.1, IC1.1 (VOUT), RESET_BUTTON.3, RESET_BUTTON.4, R_RESET.2, U2.3 (EN)
RTC_RST: U2.16 (IO18), U3.4 (!RST)
RX: TP2.TP, U2.24 (RXD0/GPIO17)
SCK: J1.13, J4.P5 (CLK), TP8.TP, U1.6 (CLK), U2.6 (IO6)
SCL: J3.1, R2_PINH.1, SENSOR2.4 (SCK), U2.20 (IO22), U3.16 (SCL), U4.7 (SCL)
SDA: J3.2, R1_PINH.1, SENSOR2.3 (SDI), U2.19 (IO21), U3.15 (SDA), U4.8 (SDA)
SRC: C4.2, D5.2 (A), L1.1, Q3.3 (D)
SS_SD: J4.P2 (CD/DAT3), U2.4 (IO4)
TX: TP1.TP, U2.25 (TXD0/GPIO16)
USB_D+: D1.1 (I/O1_1), U2.14 (IO13)
USB_D-: D1.3 (I/O2_1), U2.13 (IO12)
VBAT: C2_BAT.1, MCP73831.3 (VBAT), Q1.3 (D), TP3.TP, U4.2 (CELL), U4.3 (VDD)
VBUS: C1_BAT.1, C4_USB.1, C5_USB.1, CHG_LED.A, D1.5 (VBUS), D2.2 (ANODE), MCP73831.4 (VIN), PFMF.050.1.2, Q1.1 (G), R1_PWRUSB.2, TP14.TP
VRTC: C8.1, C10_SUPERCAP.1, R_CAPACITOR.2, U3.14 (VBAT)
VUSB: J2.A4, J2.A9, J2.B4, J2.B9, PFMF.050.1.1

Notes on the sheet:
USB C connector & ESD protection
LDO Voltage Regulator
LDO Voltage Regulator
SD Card
LI-Po Battery Charging Controller
Display Type Selector
E-Paper Drive Circuit
E-Paper Display Header
EPD Power
Environmental Sensor BME688
Voltage Supervisor + Reset & Boor I/O Button
Battery Charge Level
SPI ESD Protection Lines
Qwiic/ Stemma QT
External NOR Flash 64MB
Test Pads
RTC Module DS3231SN

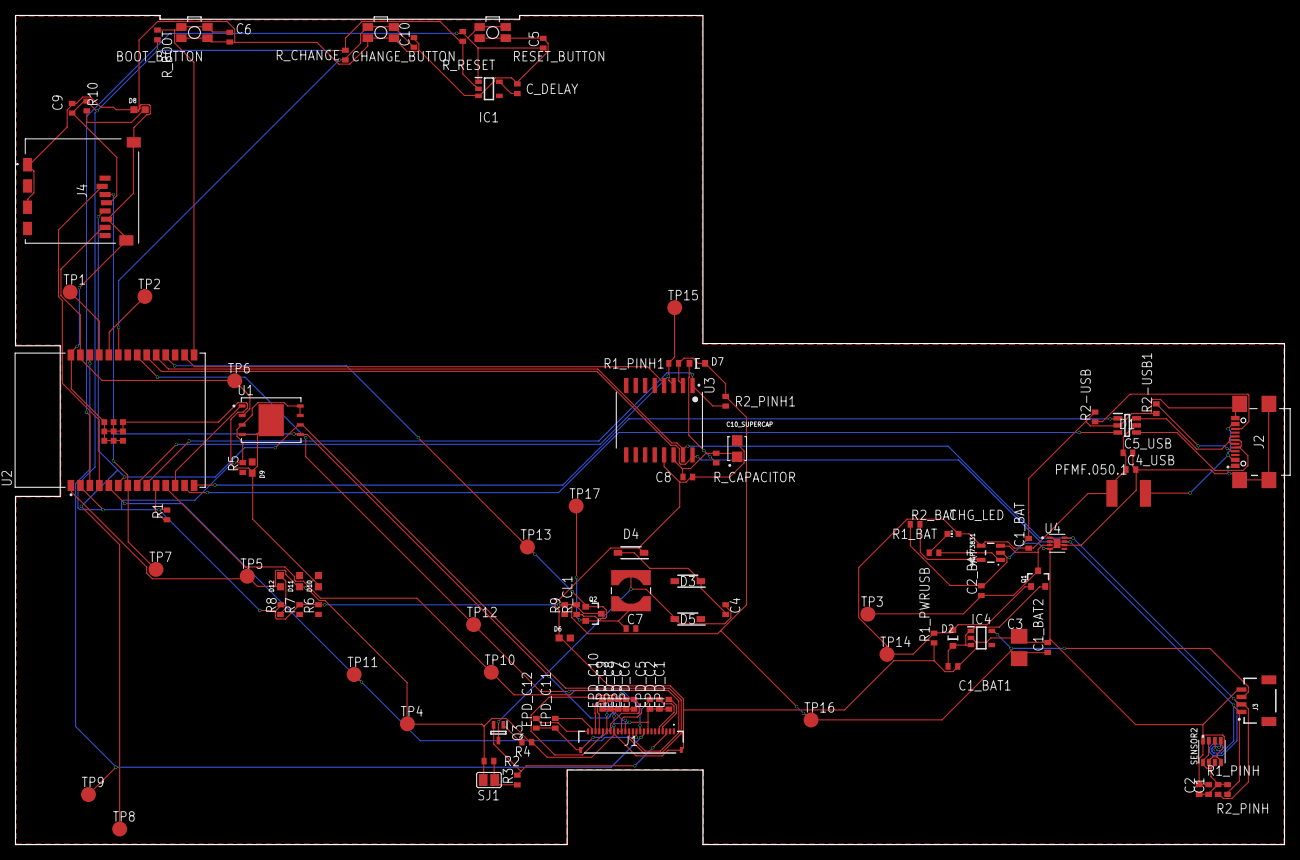
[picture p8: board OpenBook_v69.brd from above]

Board: 2 copper layers, 170.2 x 111.2 mm, 103 parts (0 on the bottom side), 58 nets.

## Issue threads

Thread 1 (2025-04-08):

[Schematic] Unconnected Pins

adinazugravescu, 2025-04-08:
Unii pini din schematic au ramas neconectati: la *SPI ESD Protection Lines* la R5-R9 si la *E-Paper Drive Circuit* la C7(trebuia conectat la un GND,  dar acum e floating).

Verifica si conecteaza corect aceste componente conform intentiei initiale a circuitului.

Radukk2, 2025-04-15:
Done

Closed 2025-04-15.

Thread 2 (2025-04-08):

[Schematic] Lipsa valori componente

adinazugravescu, 2025-04-08:
La *E-Paper Display Header*, EPD_C9 nu are valoare setata. Trebuie sa fie 1uF/50V. In plus, alte 4 condensatoare si R2 nu au nicio valoare asignata.

Completeaza valorile lipsa in schematic si in BOM, astfel incat fiecare componenta sa aiba specificata o valoare.

Closed 2025-04-15.

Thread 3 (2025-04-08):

[PCB] - Lipsa via stitching

adinazugravescu, 2025-04-08:
Nu este aplicat via stitching intre planurile de masa, in special in zona ESP32.

Adauga via-uri de stitching intre GND top si bottom, cel putin in jurul modulului ESP32 si zonele critice.

Radukk2, 2025-04-15:
Done

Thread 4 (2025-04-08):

[PCB] - Lipsa nume semnale pentru TP

adinazugravescu, 2025-04-08:
Test pad-urile nu sunt marcate in silkscreen cu numele semnalelor pe care le poarta, ceea ce le face greu de identificat la debugging sau testare.

Adauga etichete clare pe silkscreen langa fiecare test pad, cu numele semnalului respectiv(de ex. MISO, MOSI, Rx, GND, etc.).

Radukk2, 2025-04-15:
Done

Closed 2025-04-15.

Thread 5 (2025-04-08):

[Manufacturing] - Lipsa gerbers.zip

adinazugravescu, 2025-04-08:
Lipseste fisierul gerbers.zip necesar pentru productie.

Genereaza fisierele Gerber din PCB-ul final.(https://www.pcbway.com/blog/PCB_Design_Tutorial/How_to_Generate_Gerber_Files_in_Fusion_360_7c039fbf.html)

Radukk2, 2025-04-15:
Done

Closed 2025-04-15.

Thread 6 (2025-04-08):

[Mechanical] - Lipsa modele 3D

adinazugravescu, 2025-04-08:
Modelul 3D al PCB-ului nu are toate componentele pe el : D3-D6, D8-D12, Q3, C10_SUPERCAP, C3, U4, D1, SENSOR2, L1.

Cauta sau creeaza modele pentru aceste componente si asociaza-le.

Radukk2, 2025-04-15:
Done!

Closed 2025-04-15.

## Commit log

2025-04-06 all parts
    [OpenBook v38.sch, OpenBook v69.csv, OpenBook_v69.brd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]
2025-04-06 rm duplicates
    [ESP32-C6_PINS.xlsx]

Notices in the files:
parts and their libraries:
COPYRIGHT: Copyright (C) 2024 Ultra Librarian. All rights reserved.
